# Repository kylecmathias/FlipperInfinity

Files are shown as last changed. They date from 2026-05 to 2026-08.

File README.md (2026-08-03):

# Flipper Infinity - Embedded Multi-Protocol Analysis Device


*Ongoing — Hardware complete, PCB designed, firmware in active development*

A handheld multi-protocol signal analysis device built on a custom ESP32 PCB, integrating NFC/RFID, sub-GHz RF, infrared, and WiFi into a single embedded platform with an on-device touchscreen interface.

---

## Hardware

| Module | Protocol | Function |
|---|---|---|
| PN532 | SPI | NFC/RFID read/write/emulate |
| CC1101 | SPI | Sub-GHz RF (433MHz) |
| IR Transmitter | GPIO | Infrared signal transmission |
| IR Receiver | GPIO | Infrared signal capture |
| Arduino Nano ESP32 | — | Main controller, WiFi, promiscuous packet capture |
| ILI9341 TFT Touchscreen | SPI | On-device UI (XPT2046 touch controller) |
| NiMH AA x6 | — | 7.2V battery pack, onboard voltage monitoring |

Custom 2-layer PCB designed in KiCad integrating all modules on a single board with a shared SPI bus, dedicated power rails, and RF-aware layout.

---

## PCB

Designed from scratch in KiCad. Two-layer board with:
- Shared SPI bus (SCK/MOSI/MISO) daisy-chained across TFT, PN532, and CC1101
- Dedicated 1mm VCC and GND power rails
- 100nF decoupling capacitors on all RF modules
- 10µF bulk capacitor on the ESP32 3V3 rail
- Ground pour on both copper layers
- PN532 antenna keepout zone to preserve NFC read range
- CC1101 module positioned at board edge for unobstructed antenna radiation



### Pin Mapping

| Signal | ESP32 Pin | Connected To |
|---|---|---|
| SCK | D13 | TFT, PN532, CC1101 (shared SPI bus) |
| MOSI | D11 | TFT, PN532, CC1101 (shared SPI bus) |
| MISO | D12 | TFT, PN532, CC1101 (shared SPI bus) |
| TFT_SS | A2 | TFT display CS |
| T_SS | A4 | TFT touch CS |
| TFT_RST | D8 | TFT reset |
| DC | D9 | TFT data/command |
| LED | D10 | TFT backlight |
| T_IRQ | D2 | Touch interrupt |
| PN532_SS | A5 | PN532 CS |
| PN532_IRQ | D5 | PN532 interrupt |
| PN532_RST0 | D6 | PN532 reset |
| CC1101_SS | A7 | CC1101 CS |
| CC1101_GDO0 | D3 | CC1101 packet interrupt |
| IR_TX_DAT | D1 | IR transmitter |
| IR_RX_DAT | D0 | IR receiver |
| BATTERY_LVL | A3 | Battery voltage ADC (150k/100k divider) |
| BATTERY_SRC | D7 | USB/battery source detect (10k/20k divider) |
| VIN | VIN | 7.2V NiMH battery pack |

---

## Firmware

Written in C++ using ESP-IDF with FreeRTOS. Each protocol runs as an isolated task, scheduled cooperatively to avoid resource contention across shared buses.

- **Multi-protocol scheduling** — FreeRTOS tasks isolate NFC, RF, IR, and WiFi logic
- **Bus management** — SPI peripherals share the ESP32's interface without conflicts via chip select
- **Touchscreen UI** — LVGL-based interface built with SquareLine Studio for on-device workflow control
- **WiFi** — promiscuous mode packet capture for raw 802.11 frame analysis

---

## Planned Features

### WiFi
Network scanning, packet monitoring, device inventory, deauthentication, file server, MAC spoofing, captive portal, beacon spam

### Bluetooth
BLE device scanner, packet sniffer, device logger

### NFC
Read, write, emulate, sniff — supports Mifare Classic cards

### RFID
Read, write, emulate

### IR
Transmit, receive, universal remote, signal replay

### RF (CC1101)
Frequency analyzer, listen, decode, replay, transmit

---

## Repository Structure

```
FlipperInfinity/
├── include/                # Header files to include (.hpp)
├── src/                    # Firmware source (.cpp, ESP-IDF) and build files (CMakeLists, idf_component)
│   ├── ui/                 # UI files generated with EEZ Studio (.c, .h)
├── hardware/
│   ├── schematic/          # KiCad schematic (.kicad_sch)
│   ├── pcb/                # KiCad PCB layout (.kicad_pcb)
│   └── gerbers/
│       └── v1.0/           # Manufacturing files for JLCPCB
├── partitions.csv          # ESP32s3 partitions
├── sdkconfig.defaults      # Configuration overrides
├── platformio.ini          # Platformio configuration
└── README.md
```

---

## Tech Stack

ESP32 · ESP-IDF · FreeRTOS · LVGL · SquareLine Studio · C++ · SPI · PN532 · CC1101 · KiCad

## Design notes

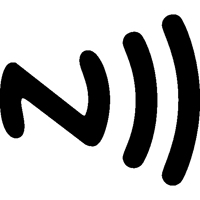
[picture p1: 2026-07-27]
ui/assets/NFC.png

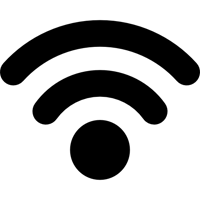
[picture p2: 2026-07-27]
ui/assets/WIFI.png

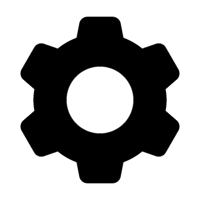
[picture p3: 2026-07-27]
ui/assets/settings.png

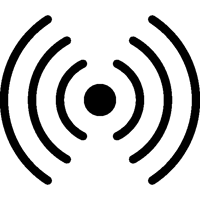
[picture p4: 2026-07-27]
ui/assets/RFID.png

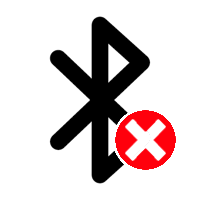
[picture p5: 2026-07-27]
ui/assets/NO BLUETOOTH.png

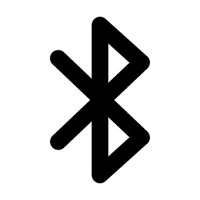
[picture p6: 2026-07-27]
ui/assets/BLUETOOTH.png

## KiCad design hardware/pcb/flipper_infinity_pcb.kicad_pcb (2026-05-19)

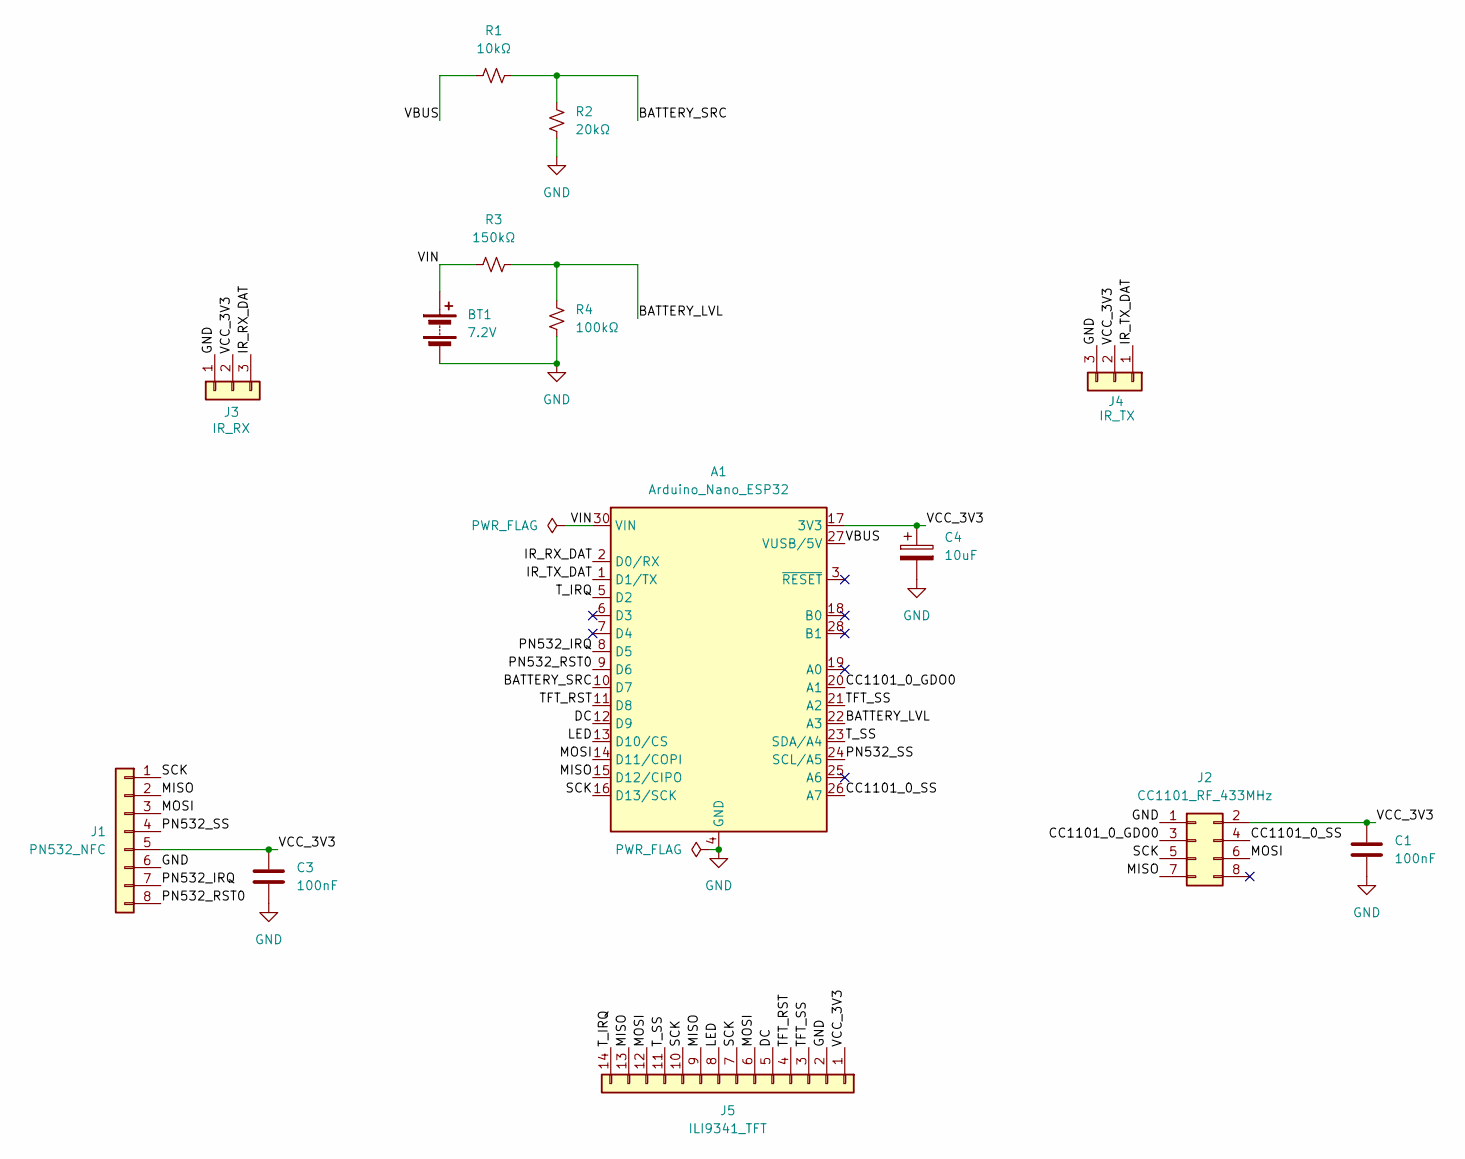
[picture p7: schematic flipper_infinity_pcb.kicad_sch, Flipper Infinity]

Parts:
A1: Arduino_Nano_ESP32; Arduino_Nano
BT1: 7.2V; PinHeader_1x02_P2.54mm_Vertical
C1, C3: 100nF; C_0805_2012Metric
C4: 10uF; CP_Radial_D5.0mm_P2.00mm
J1: PN532_NFC; PinHeader_1x08_P2.54mm_Vertical
J2: CC1101_RF_433MHz; PinHeader_2x04_P2.54mm_Vertical
J3: IR_RX; PinHeader_1x03_P2.54mm_Vertical
J4: IR_TX; PinHeader_1x03_P2.54mm_Vertical
J5: ILI9341_TFT; PinHeader_1x14_P2.54mm_Vertical
R1: 10kΩ; R_Axial_DIN0207_L6.3mm_D2.5mm_P10.16mm_Horizontal
R2: 20kΩ; R_Axial_DIN0207_L6.3mm_D2.5mm_P10.16mm_Horizontal
R3: 150kΩ; R_Axial_DIN0207_L6.3mm_D2.5mm_P10.16mm_Horizontal
R4: 100kΩ; R_Axial_DIN0207_L6.3mm_D2.5mm_P10.16mm_Horizontal

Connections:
/BATTERY_LVL: A1.22 (A3), R3.2, R4.2
/BATTERY_SRC: A1.10 (D7), R1.2, R2.1
/CC1101_0_GDO0: A1.20 (A1), J2.3
/CC1101_0_SS: A1.26 (A7), J2.4
/DC: A1.12 (D9), J5.5
/IR_RX_DAT: A1.2 (D0/RX), J3.3
/IR_TX_DAT: A1.1 (D1/TX), J4.1
/LED: A1.13 (D10/CS), J5.8
/MISO: A1.15 (D12/CIPO), J1.2, J2.7, J5.9, J5.13
/MOSI: A1.14 (D11/COPI), J1.3, J2.6, J5.6, J5.12
/PN532_IRQ: A1.8 (D5), J1.7
/PN532_RST0: A1.9 (D6), J1.8
/PN532_SS: A1.24 (SCL/A5), J1.4
/SCK: A1.16 (D13/SCK), J1.1, J2.5, J5.7, J5.10
/TFT_RST: A1.11 (D8), J5.4
/TFT_SS: A1.21 (A2), J5.3
/T_IRQ: A1.5 (D2), J5.14
/T_SS: A1.23 (SDA/A4), J5.11
/VBUS: A1.27 (VUSB/5V), R1.1
/VCC_3V3: A1.17 (3V3), C1.1, C3.1, C4.1, J1.5, J2.2, J3.2, J4.2, J5.1
/VIN: A1.30 (VIN), BT1.1 (+), R3.1
GND: A1.4 (GND), A1.29 (GND), BT1.2 (-), C1.2, C3.2, C4.2, J1.6, J2.1, J3.1, J4.3, J5.2, R2.2, R4.1

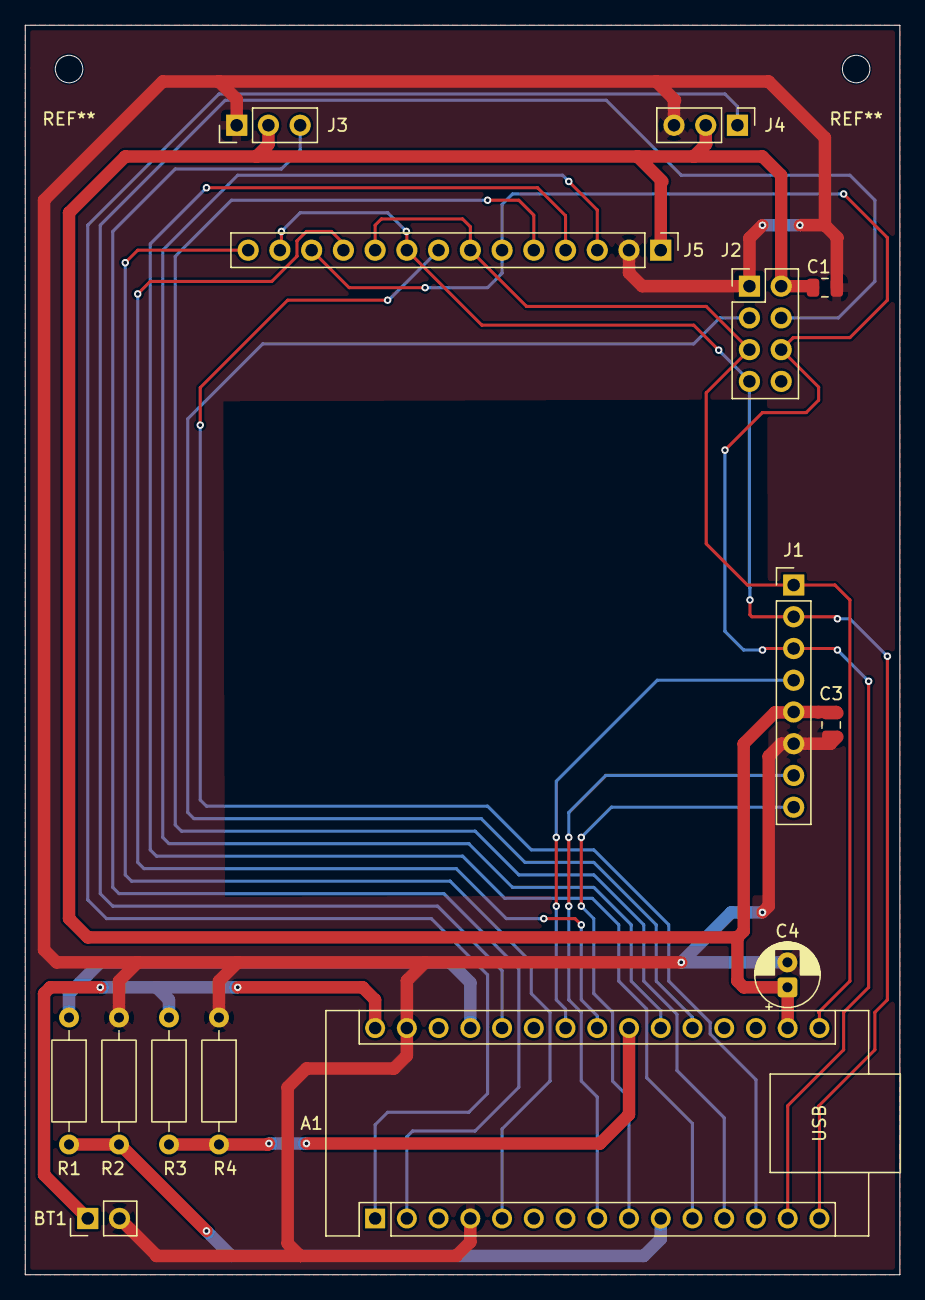
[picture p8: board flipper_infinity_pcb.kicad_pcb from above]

Board: 2 copper layers, 70.0 x 100.0 mm, 14 parts (0 on the bottom side), 22 nets.

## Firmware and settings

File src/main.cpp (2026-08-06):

#include "ui_bridge.hpp"
#include "main_menu.hpp"
#include "bluetooth_menu.hpp"
#include "wifi_menu.hpp"
#include "nfc_menu.hpp"
#include "ir_menu.hpp"

adc_oneshot_unit_handle_t adc1_handle = nullptr;

extern "C" {
    void app_main(void);
    //bool __wrap_ieee80211_raw_frame_sanity_check(void *frame, int length) { return true; }
    void* lv_psram_malloc(size_t size) { return heap_caps_malloc(size, MALLOC_CAP_SPIRAM); }
    void* lv_psram_realloc(void* ptr, size_t size) { return heap_caps_realloc(ptr, size, MALLOC_CAP_SPIRAM); }
}

void init_fs() {
    esp_vfs_littlefs_conf_t conf = {
        .base_path = LITTLEFS_MOUNT,
        .partition_label = LITTLEFS_PART_LABEL,
        .format_if_mount_failed = true
    };

    esp_err_t ret = esp_vfs_littlefs_register(&conf);
    if (ret != ESP_OK) {
        printf("Failed to mount LittleFS (%s)", esp_err_to_name(ret));
    }
}

void touch_calibration(esp_lcd_touch_handle_t tp, uint16_t *x, uint16_t *y, uint16_t *strength, uint8_t *point_num, uint8_t max_point_num) {
    if (*point_num > 0) {
        float raw_x = *x;
        float raw_y = *y;

        float x_multiplier = LCD_X_MULTIPLIER;
        float y_multiplier = LCD_Y_MULTIPLIER; 

        int adjusted_x = (raw_x * x_multiplier) - LCD_X_OFFSET; 
        int adjusted_y = (raw_y * y_multiplier) - (raw_y < Y_DRIFT_END ? LCD_Y_OFFSET : 0); 


        if (adjusted_x < 0) adjusted_x = 0;
        if (adjusted_x > LCD_H_RES - 1) adjusted_x = LCD_H_RES - 1;
        if (adjusted_y < 0) adjusted_y = 0;
        if (adjusted_y > LCD_V_RES - 1) adjusted_y = LCD_V_RES - 1;

        *x = adjusted_x;
        *y = adjusted_y;
    }
}

void init_tft() {
    printf("Initializing TFT\n");

    //initialize spi bus
    spi_bus_config_t buscfg = {};
    buscfg.sclk_io_num = GPIO_PINS::SCK;
    buscfg.mosi_io_num = GPIO_PINS::MOSI;
    buscfg.miso_io_num = GPIO_PINS::MISO;
    buscfg.quadwp_io_num = -1;
    buscfg.quadhd_io_num = -1;
    buscfg.max_transfer_sz = LCD_H_RES * 80 * sizeof(uint16_t);

    spi_bus_initialize(LCD_HOST, &buscfg, SPI_DMA_CH_AUTO);

    //initialize tft screen
    esp_lcd_panel_io_handle_t io_handle = nullptr;
    esp_lcd_panel_io_spi_config_t io_config = {};
    io_config.dc_gpio_num = GPIO_PINS::TFT_DC;
    io_config.cs_gpio_num = GPIO_PINS::TFT_SS;
    io_config.pclk_hz = LCD_PIXEL_CLK;
    io_config.lcd_cmd_bits = 8;
    io_config.lcd_param_bits = 8;
    io_config.spi_mode = 0;
    io_config.trans_queue_depth = 10;

    esp_lcd_new_panel_io_spi(static_cast<esp_lcd_spi_bus_handle_t>(LCD_HOST), &io_config, &io_handle);

    //add the tfts chip
    esp_lcd_panel_handle_t panel_handle = nullptr;
    esp_lcd_panel_dev_config_t panel_config = {};
    panel_config.reset_gpio_num = GPIO_PINS::TFT_RST;
    panel_config.rgb_ele_order = LCD_RGB_ELEMENT_ORDER_BGR;
    panel_config.bits_per_pixel = 16;

    esp_lcd_new_panel_ili9341(io_handle, &panel_config, &panel_handle);
    esp_lcd_panel_reset(panel_handle);
    esp_lcd_panel_init(panel_handle);
    esp_lcd_panel_disp_on_off(panel_handle, true);

    //initialize the tfts touch controller
    esp_lcd_panel_io_handle_t tp_io_handle = nullptr;
    esp_lcd_panel_io_spi_config_t tp_io_config = {};
    tp_io_config.cs_gpio_num = GPIO_PINS::TOUCH_SS;
    tp_io_config.pclk_hz = LCD_TOUCH_CLK;
    tp_io_config.spi_mode = 0;
    tp_io_config.lcd_cmd_bits = 8;
    tp_io_config.lcd_param_bits = 0;
    tp_io_config.trans_queue_depth = 3;

    esp_lcd_new_panel_io_spi(static_cast<esp_lcd_spi_bus_handle_t>(LCD_HOST), &tp_io_config, &tp_io_handle);

    esp_lcd_touch_handle_t tp = nullptr;
    esp_lcd_touch_config_t tp_cfg = {};
    tp_cfg.x_max = LCD_H_RES;
    tp_cfg.y_max = LCD_V_RES;
    tp_cfg.rst_gpio_num = GPIO_PINS::NONE;
    tp_cfg.int_gpio_num = GPIO_PINS::TOUCH_IRQ;
    tp_cfg.flags.swap_xy = 0;  
    tp_cfg.flags.mirror_x = 1; 
    tp_cfg.flags.mirror_y = 0;
    tp_cfg.process_coordinates = touch_calibration;

    esp_lcd_touch_new_spi_xpt2046(tp_io_handle, &tp_cfg, &tp);

    //initialize lvgl
    lvgl_port_cfg_t lvgl_cfg = ESP_LVGL_PORT_INIT_CONFIG();
    lvgl_cfg.task_affinity = 1;    
    lvgl_cfg.task_priority = 4;
    lvgl_port_init(&lvgl_cfg);

    //pass the screen to lvgl
    lvgl_port_display_cfg_t disp_cfg = {};
    disp_cfg.io_handle = io_handle;
    disp_cfg.panel_handle = panel_handle;
    disp_cfg.buffer_size = LCD_H_RES * 40;
    disp_cfg.hres = LCD_H_RES;
    disp_cfg.vres = LCD_V_RES;
    disp_cfg.rotation.swap_xy = false;
    disp_cfg.rotation.mirror_x = false;
    disp_cfg.rotation.mirror_y = true;
    lv_disp_t *disp = lvgl_port_add_disp(&disp_cfg);

    //pass the touch panel
    lvgl_port_touch_cfg_t touch_cfg = {};
    touch_cfg.disp = disp;
    touch_cfg.handle = tp;
    lvgl_port_add_touch(&touch_cfg);

    printf("TFT initialized\n");
}

void init_wifi() {
    printf("Initializing Wifi\n");
    esp_err_t ret = nvs_flash_init();
    if (ret == ESP_ERR_NVS_NO_FREE_PAGES || ret == ESP_ERR_NVS_NEW_VERSION_FOUND) {
        ESP_ERROR_CHECK(nvs_flash_erase());
        ret = nvs_flash_init();
    }
    ESP_ERROR_CHECK(ret);

    ESP_ERROR_CHECK(esp_netif_init());
    ESP_ERROR_CHECK(esp_event_loop_create_default());
    esp_netif_t *sta_netif = esp_netif_create_default_wifi_sta();
    esp_netif_set_hostname(sta_netif, DISPLAY_HOSTNAME);

    wifi_init_config_t wifi_cfg = WIFI_INIT_CONFIG_DEFAULT();
    ESP_ERROR_CHECK(esp_wifi_init(&wifi_cfg));

    esp_wifi_set_mode(WIFI_MODE_STA);

    ESP_ERROR_CHECK(esp_event_handler_instance_register(WIFI_EVENT, WIFI_EVENT_SCAN_DONE, &wifi_scan_done_handler, nullptr, nullptr));
    ESP_ERROR_CHECK(esp_event_handler_instance_register(WIFI_EVENT, WIFI_EVENT_STA_DISCONNECTED, &wifi_connection_handler, nullptr, nullptr));
    ESP_ERROR_CHECK(esp_event_handler_instance_register(IP_EVENT, IP_EVENT_STA_GOT_IP, &wifi_connection_handler, nullptr, nullptr));

    esp_wifi_start();

    printf("Wifi initialized\n");
}

void init_bluetooth() {
    ESP_ERROR_CHECK(esp_bt_controller_mem_release(ESP_BT_MODE_CLASSIC_BT));

    ESP_ERROR_CHECK(nimble_port_init());

    int rc = ble_svc_gap_device_name_set("FlipperInfinity");
    assert(rc == 0);

    nimble_port_freertos_init(ble_host_task);
}

// void init_ir() {
//     rmt_tx_channel_config_t tx_chan_cfg = {
//         .gpio_num = GPIO_PINS::IR_TX,
//         .clk_src = RMT_CLK_SRC_DEFAULT,
//         .resolution_hz = IR_RES_HZ,
//         .mem_block_symbols = 64,
//         .trans_queue_depth = 4,
//         .flags = {
//             .invert_out = 0,
//             .with_dma = 0
//         }
//     };
//     ESP_ERROR_CHECK(rmt_new_tx_channel(&tx_chan_cfg, &ir_tx_channel));

//     rmt_carrier_config_t carrier_cfg = {
//         .frequency_hz = IR_TX_CARRIER_FREQ_HZ,
//         .duty_cycle = IR_TX_CARRIER_DUTY,
//         .flags = {
//             .polarity_active_low = 0,
//             .always_on = 0
//         }
//     };
//     ESP_ERROR_CHECK(rmt_apply_carrier(ir_tx_channel, &carrier_cfg));
//     ESP_ERROR_CHECK(rmt_enable(ir_tx_channel));

//     rmt_rx_channel_config_t rx_chan_cfg = {
//         .gpio_num = GPIO_PINS::IR_RX,
//         .clk_src = RMT_CLK_SRC_DEFAULT,
//         .resolution_hz = IR_RES_HZ,
//         .mem_block_symbols = 64,
//         .flags = {
//             .with_dma = 0
//         }
//     };
//     ESP_ERROR_CHECK(rmt_new_rx_channel(&rx_chan_cfg, &ir_rx_channel));

//     rmt_receive_config_t receive_cfg = {
//         .signal_range_min_ns = 10000,
//         .signal_range_max_ns = 12000 * 1000,
//         .flags = {
//             .en_partial_rx = 0
//         }
//     };
// }

void init_pins() {
    esp_err_t isr_err = gpio_install_isr_service(0);
    if (isr_err != ESP_OK && isr_err != ESP_ERR_INVALID_STATE) {
        printf("Failed to install GPIO ISR service: %s\n", esp_err_to_name(isr_err));
    }

    gpio_config_t batt_src_conf = {
        .pin_bit_mask = (1ULL << GPIO_PINS::BATT_SRC),
        .mode = GPIO_MODE_INPUT,
        .pull_up_en = GPIO_PULLUP_DISABLE,
        .pull_down_en = GPIO_PULLDOWN_ENABLE,
        .intr_type = GPIO_INTR_DISABLE
    };
    gpio_config(&batt_src_conf);

    gpio_config_t tft_bkl_conf = {
        .pin_bit_mask = (1ULL << GPIO_PINS::TFT_BKL),
        .mode = GPIO_MODE_OUTPUT,
        .pull_up_en = GPIO_PULLUP_ENABLE,
        .pull_down_en = GPIO_PULLDOWN_DISABLE,
        .intr_type = GPIO_INTR_DISABLE
    };
    gpio_config(&tft_bkl_conf);
    gpio_set_level(GPIO_PINS::TFT_BKL, HIGH);

    adc_oneshot_unit_init_cfg_t init_config1 = {
        .unit_id = ADC_UNIT_1,
        .clk_src  = static_cast<adc_oneshot_clk_src_t>(0),                      
        .ulp_mode = ADC_ULP_MODE_DISABLE
    };
    ESP_ERROR_CHECK(adc_oneshot_new_unit(&init_config1, &adc1_handle));

    adc_oneshot_chan_cfg_t config = {
        .atten = ADC_ATTEN_DB_12,
        .bitwidth = ADC_BITWIDTH_DEFAULT
    };
    ESP_ERROR_CHECK(adc_oneshot_config_channel(adc1_handle, ADC_CHANNEL_3, &config));
}

void app_main(void) {
    vTaskDelay(pdMS_TO_TICKS(500));
    init_pins();
    init_fs();
    init_wifi();
    init_bluetooth();

    init_psram_oui_database();

    vTaskDelay(pdMS_TO_TICKS(10));
    init_tft();

    // pn532_t* device = nullptr;
    // init_nfc(device);
    init_nfc();

    lvgl_port_lock(0);
    ui_init();
    lvgl_port_unlock();

    vTaskDelay(pdMS_TO_TICKS(10));
    set_initial_flags();

    init_wifi_menu();
    init_bluetooth_menu();
    init_nfc_menu();

    loadScreen(SCREEN_ID_LOGO);

    vTaskDelete(NULL);
}

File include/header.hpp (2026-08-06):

#pragma once

#include <stdio.h>
#include <sys/stat.h>

#include <string>
#include <atomic>
#include <optional>
#include <array>
#include <format>

#include <freertos/FreeRTOS.h>
#include <freertos/task.h>
#include <freertos/event_groups.h>
#include <freertos/semphr.h>
#include <freertos/queue.h>

#include <driver/spi_master.h>
#include <driver/gpio.h>
#include <esp_littlefs.h>
#include <esp_heap_caps.h>
#include <esp_random.h>
#include <esp_timer.h>
#include <esp_private/periph_ctrl.h>

#include <esp_adc/adc_oneshot.h>
#include <esp_adc/adc_cali.h>
#include <esp_adc/adc_cali_scheme.h>

#include <esp_lcd_panel_io.h>
#include <esp_lcd_panel_vendor.h>
#include <esp_lcd_panel_ops.h>
#include <esp_lcd_ili9341.h>
#include <esp_lcd_touch_xpt2046.h>
#include <esp_lvgl_port.h>

#include <nvs_flash.h>
#include <esp_mac.h>
#include <esp_netif.h>
#include <esp_event.h>
#include <esp_wifi_default.h>
#include <esp_wifi.h>
#include <esp_log.h>
#include <esp_system.h>
#include <esp_netif_net_stack.h>
#include <lwip/sockets.h>
#include <lwip/etharp.h>
#include <lwip/netif.h>
#include <lwip/ip4_addr.h>
#include <mdns.h>

#include <esp_bt.h>
#include <esp_nimble_hci.h>
#include <nimble/nimble_port.h>
#include <nimble/nimble_port_freertos.h>
#include <host/ble_hs.h>
#include <host/ble_gap.h>
#include <host/ble_hs_adv.h>
#include <host/util/util.h>
#include <services/gap/ble_svc_gap.h>
#include <pn532_driver.hpp>

#include <rom/ets_sys.h>

#include <driver/rmt_tx.h>
#include <driver/rmt_rx.h>

#include "helpers.hpp"

inline constexpr const char* LITTLEFS_MOUNT = "/flipperinf";
inline constexpr const char* LITTLEFS_PART_LABEL = "storage";
inline constexpr size_t FILENAME_LEN = 64;
inline constexpr size_t FILEPATH_LEN = 128;

inline constexpr uint8_t HIGH = 1;
inline constexpr uint8_t LOW = 0;

inline constexpr const char* DISPLAY_HOSTNAME = "iPhone";
inline constexpr size_t HOSTNAME_LEN = 32;

inline constexpr size_t LINE_BUFFER_LEN = 128;

inline constexpr spi_host_device_t LCD_HOST = SPI2_HOST;
inline constexpr uint64_t LCD_PIXEL_CLK = (40 * 1000 * 1000);
inline constexpr uint64_t LCD_TOUCH_CLK = (2 * 1000 * 1000);
inline constexpr uint16_t LCD_H_RES = 240;
inline constexpr uint16_t LCD_V_RES = 320;
inline constexpr float LCD_X_MULTIPLIER = 1.00f;
inline constexpr float LCD_Y_MULTIPLIER = 1.00f;
inline constexpr int16_t LCD_X_OFFSET = 0;
inline constexpr int16_t LCD_Y_OFFSET = 15;
inline constexpr uint16_t Y_DRIFT_END = 199;
inline constexpr uint16_t X_DRIFT_START = 320;
inline constexpr uint8_t ADC_SAMPLES = 8;
inline constexpr float V_MAX = 3.3f;
inline constexpr uint8_t ADC_RES = 12;
inline constexpr uint16_t ADC_MAX = (1UL << ADC_RES) - 1;
inline constexpr uint16_t BATT_ADC_MAX = ADC_MAX;
inline constexpr uint16_t BATT_ADC_MIN = 2.4f * ADC_MAX / V_MAX;

inline constexpr size_t MAX_SCAN_NETWORKS = 40;
inline constexpr size_t MAX_INVENTORY_DEVICES = 256;
inline constexpr size_t MAC_STR_LEN = 18;
inline constexpr size_t MANUFACTURER_STR_LEN = 32;
inline constexpr int8_t RSSI_MIN = -100;
inline constexpr int8_t RSSI_MAX = -20;
inline constexpr size_t MAX_UUIDS16 = 4;

inline constexpr spi_host_device_t PN532_HOST = SPI2_HOST;
inline constexpr uint32_t PN532_CLK = 2500000;

namespace GPIO_PINS {
    static constexpr gpio_num_t NONE = GPIO_NUM_NC;

    static constexpr gpio_num_t SCK = GPIO_NUM_48; //D13
    static constexpr gpio_num_t MOSI = GPIO_NUM_38; //D11
    static constexpr gpio_num_t MISO = GPIO_NUM_47; //D12

    static constexpr gpio_num_t TFT_SS = GPIO_NUM_3; //A2
    static constexpr gpio_num_t TFT_DC = GPIO_NUM_18; //D9
    static constexpr gpio_num_t TFT_RST = GPIO_NUM_17; //D8
    static constexpr gpio_num_t TFT_BKL = GPIO_NUM_21; //D10 but rn is on 3V3

    static constexpr gpio_num_t TOUCH_SS = GPIO_NUM_11; //A4
    static constexpr gpio_num_t TOUCH_IRQ = GPIO_NUM_5; //D2
    
    static constexpr gpio_num_t CC1101_SS = GPIO_NUM_14; //A7
    static constexpr gpio_num_t CC1101_GDO0 = GPIO_NUM_6; //A1

    static constexpr gpio_num_t PN532_SS = GPIO_NUM_12; //A5
    static constexpr gpio_num_t PN532_IRQ = GPIO_NUM_8; //D5
    static constexpr gpio_num_t PN532_RST = GPIO_NUM_9; //D6

    static constexpr gpio_num_t IR_RX = GPIO_NUM_44; //D0
    static constexpr gpio_num_t IR_TX = GPIO_NUM_43; //D1

    static constexpr gpio_num_t BATT_SRC = GPIO_NUM_10; //D7
    static constexpr gpio_num_t BATT_LVL = GPIO_NUM_4; //A3
};

inline constexpr uint8_t BATTERY_LEVEL_MIN = 0;
inline constexpr uint8_t BATTERY_LEVEL_MAX = 100;

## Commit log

2026-05-19 added pcb files
    [flipper_infinity_pcb-B_Courtyard.gbr, flipper_infinity_pcb-B_Cu.gbl, flipper_infinity_pcb-B_Mask.gbs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]
2026-07-27 switched to platformio
    [partitions.csv]
2026-08-03 nfc menu
    [partitions.csv]
2026-08-06 wrote custom pn532 driver to fix spi deadlock
    [header.hpp, main.cpp, nfc_menu.cpp]
